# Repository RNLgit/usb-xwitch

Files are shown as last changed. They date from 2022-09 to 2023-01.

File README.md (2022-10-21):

# USB Hub

A programmable budget USB 1:2 multiplexer and HUB device (original name usb-xwitch). Features one 1:2 USB 3.1 switch and 4 Ch USB 2.0 remote 
controllable HUB. Controlling via on board micro USB or by Raspberry Pi UART. 

## CAD Setup (KiCad 6.0)

- Open ./sch/usb_xwitch.kicad_pro -> Schematics Editor 
- in Preferences -> Configure Path, add path name: "USB_XWITCH" and path: absolute address of the project (e.g. /Users/runnanl/src/usb-hub)

1. Channel Features

- Switch: USB 3.0 High Speed 1 Mux 2 switching. Additional physical control by push button switch.
- HUB: USB 2.0 HS 1:4 HUB. Individual remote control, power delivery and over current shutdown.
- HUB Expansion: UART daisy chain HUB capability.

2. Command via micro USB serial (default) or use by UART from Raspberry Pi (as a HAT)

## CAD Setup (KiCad 6.0)

- Open ./sch/usb_xwitch.kicad_pro -> Schematics Editor 
- in Preferences -> Configure Path, add path name: "USB_XWITCH" and path: absolute address of the project (e.g. /Users/runnanl/src/usb-hub)

## Hardware Overview

version: v0.2

PCBA front
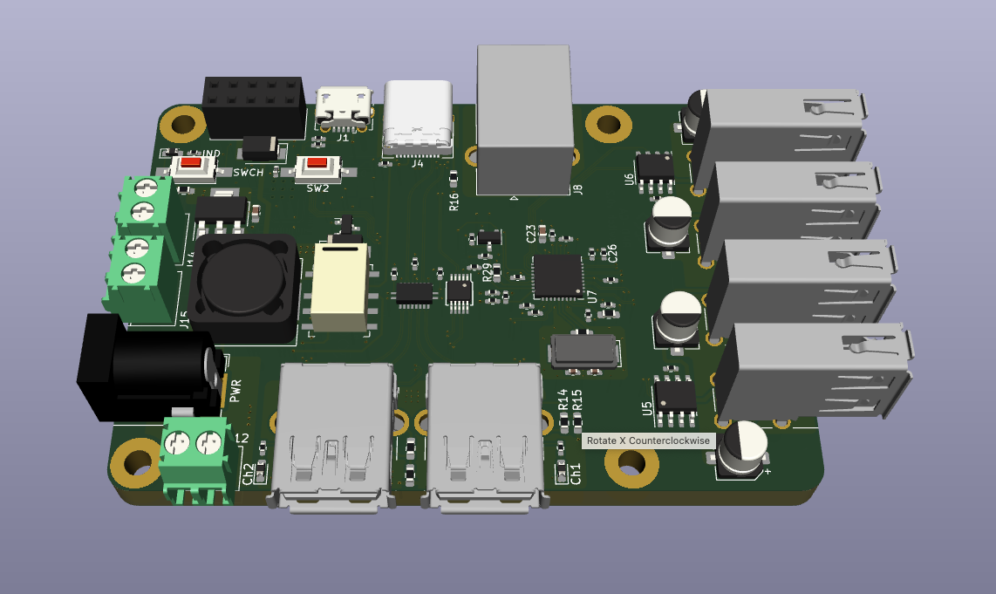
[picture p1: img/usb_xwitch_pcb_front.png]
HardwareOverview (front)


PCBA rear
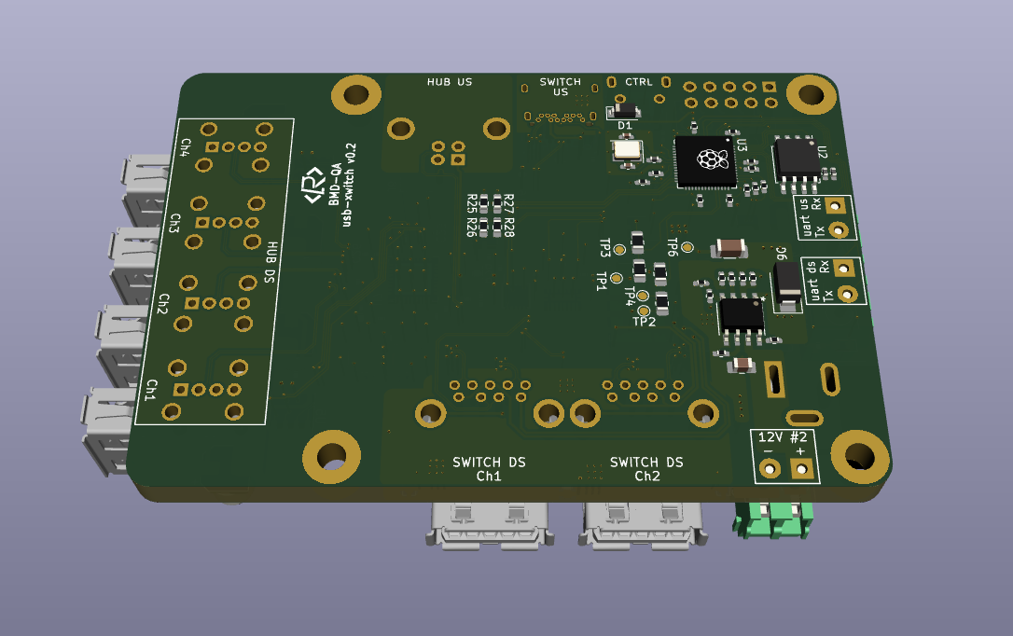
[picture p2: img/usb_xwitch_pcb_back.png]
HardwareOverview (back)


- CHS: USB3.0 1 mux 2. Port active indications. Switch button.
- CHH: USB2.0 HS 1x upstream USB-B to 4x downstream USB-A ports. Control via commands.
- Raspberry Pi compaticable header (10 Pins).
- Mountable as Raspberry Pi 2/3/4 HAT.

Power Supply:

12V 2A supplied by barrel jack (default unmounted) OR PWR screw terminal. Alternatively, 5V 3A DC power can directly
power 5V points from 10 Pin header. 

> **WARNING** : Only one power supply connected at the same time

## Software Overview

- pico software
- USB control protocols and commands
- UART control commands

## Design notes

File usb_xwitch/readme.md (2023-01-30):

# USB-Xwitch Python Package

pico controller and communication package

- pico: code flash to board
- commsrepl: controlling command via pico onboard usb with repl communication over py
- commsrpi: communication via UART header (J8) to raspberry pi

## Flash pico controller

Flash pico uses python ```rshell``` to copy files into internal memory

use rshell to flash ./pico files to the board
1. ```pip install rshell``` (need to be in Python environment)
2. ```rshell -p port_name``` (or simply ```rshell``` if this is the only board connected)
    
   e.g.:
   
    Windows: ```rshell -p COMX```

   Linux / macOS: ```rshell -p /dev/tty.usbmodem11201```

3. Copy firmware files:
    - ```cp main.py /pyboard/main.py```
    - ```cp conf.py /pyboard/conf.py```
5. power cycle pico

   ### validation
   1. connect to pico 
      
      Windows: putty -> Serial --> COM port and connect
      
      macOS: ```minicom -D /dev/tty.usbmodem1234546```
   
   2. flip on off of pico onboard led. Visual check on board.
      ```console
      >>> flip_indicator_led()
      ```
   
## Communications

1. Direct commanding over serial 
    - macOS
      - install ```minicom``` (```brew install minicom```)
      - get divece name by: ```ls /dev/tty*```
      - connect device by: ```minicom -D /dev/tty.usbmodel123456```
      - enjoy!
    - Windows
      - install PuTTY
      - open PuTTY, go to serial, enter board port COMx appear in device manager
      - enjoy!
2. As a python package (under construction)
    - install python package 
    ```pip install -e ./usb_xwitch/comms-repl```
    - Working in progress...

## Commands

Commands available via ``` print(__doc__)``` when communication established

Single hub functions:

```set_hub(list)```: set hub 4 channels on/off. format: ```[bool, bool, bool, bool]```

```get_hub()```: get current hub 4 channels in tuple

```set_switch(int)```: set switch to channel 1 / 2. starting from 0

```get_switch()```: get current switch channel

```get_adc(int)```: get current switch bus 1 / 2 volrage reading

```flip_indicator_led()```: flip indicator led to opposite state

```ind_led(bool)```: bool. set indicator led status

Daisy chain hub functions:

```discovery_chain()```: use currrent hub as root hub, discovery all available downstream daisychain-able hubs

```set_hub_chain(*args)```: set daisy chain hubs on/off (bool list). None to escape. e.g. set_hub_chain([True, False, False], None, [True, True, True, True]) set hub0 channel 1 on, channel 2 and 3 off (channel 4 used to chain next hub); keep hub1 unchanged; set hub2 all 4 channels on.

```set_hubs(bool)```: set all hub channels on the chain on / off, except for the channel used for chaining next hub. (default ch4)

```get_hubs()```: get all hubs on off status in a dictionary. dictionary syntax: {channel_no: [bool_list]}

```get_hub_chain(int)```: get a hub channel on off status list by its index number. root hub index starting from 0

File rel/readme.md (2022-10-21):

Release and manufacturing directory.

## Directory guide:

- bom_x: BoM file with fields of: Comment, Designator, Footprint, LCSC (pcba manufacturer specific)
- gerber_x: gerber files, drill files, drill map files
- cpl_x: component placement files for PCBA. Fields: Designator, Val, Package, Mid X, Mid Y, Rotation, Layer

## Fabrication Generation Guide:

- Follow the [guide](https://support.jlcpcb.com/article/194-how-to-generate-gerber-and-drill-files-in-kicad-6) to generate gerber and drill
- Follow the [guide](https://support.jlcpcb.com/article/84-how-to-generate-the-bom-and-centroid-file-from-kicad) to generate BoM and CPL for PCBA

## Uploading:

- zip gerber into single file and upload
- upload bom file if required PCBA
- upload cpl file if required PCBA

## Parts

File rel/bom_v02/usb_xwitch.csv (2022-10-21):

Comment | Designator | Footprint | LCSC part number
100n | C1,C2,C3,C4,C5,C6,C7,C8,C9,C10,C11,C18,C19,C20,C21,C22,C24,C25,C27,C28,C29,C30,C37,C38,C41 | Resistor_SMD:R_0402_1005Metric_Pad0.72x0.64mm_HandSolder | C1525
1u | C12,C13,C26,C32 | Resistor_SMD:R_0402_1005Metric_Pad0.72x0.64mm_HandSolder | C52923
2.2u | C14 | Inductor_SMD:L_0402_1005Metric_Pad0.77x0.64mm_HandSolder | C12530
100n | C15 | Inductor_SMD:L_0402_1005Metric_Pad0.77x0.64mm_HandSolder | C1525
30pF | C16,C17 | Capacitor_SMD:C_0402_1005Metric_Pad0.74x0.62mm_HandSolder | C1570
4.7u | C23 | Capacitor_SMD:C_0603_1608Metric_Pad1.08x0.95mm_HandSolder | C19666
100u | C31,C33,C36,C40 | Capacitor_SMD:CP_Elec_5x5.4 | C87867
27p | C35,C39 | Capacitor_SMD:C_0402_1005Metric_Pad0.74x0.62mm_HandSolder | C1557
22u | C42 | Capacitor_SMD:C_1206_3216Metric_Pad1.33x1.80mm_HandSolder | C12891
10u | C43 | Capacitor_SMD:C_0805_2012Metric_Pad1.18x1.45mm_HandSolder | C440198
150pF | C44 | Resistor_SMD:R_0402_1005Metric_Pad0.72x0.64mm_HandSolder | C1527
10u | C45,C46 | Capacitor_SMD:C_0603_1608Metric_Pad1.08x0.95mm_HandSolder | C96446
B5819W SL | D1 | Diode_SMD:D_SOD-123 | C8598
19-217/GHC-YR1S2/3T | D2,D4,D5,D8,D9,D10,D11,D12 | Diode_SMD:D_0603_1608Metric_Pad1.05x0.95mm_HandSolder | C72043
SS34 | D3,D6,D7 | Diode_SMD:D_SMA | C8678
RPI Mounting Hole | H1,H2,H3,H4 | MountingHole:MountingHole_3.2mm_M3_Pad
USB_B_Micro | J1 | Connector_USB:USB_Micro-B_Molex-105017-0001 | C10418
DNF | J11 | Connector_PinHeader_1.00mm:PinHeader_1x04_P1.00mm_Vertical_SMD_Pin1Left
Screw_Terminal_3.5mm | J12,J14,J15 | TerminalBlock_4Ucon:TerminalBlock_4Ucon_1x02_P3.50mm_Horizontal | C466970
Conn_02x05_Odd_Even | J13 | Connector_PinSocket_2.54mm:PinSocket_2x05_P2.54mm_Vertical
Barrel_Jack_Switch_Pin3Ring | J2 | usb_xwitch:BarrelJack_SCD556DCS113BM3G
USB3_A | J3,J5 | usb_xwitch:USB3_A_AdamTech_USB-A3-S-RA | C69073
USB_C_Receptacle | J4 | usb_xwitch:USB_TypeC_24Pin_ShouHan | C456013
USB_A | J6,J7,J9,J10 | Connector_USB:USB_A_Wuerth_614004134726_Horizontal | C720524
USB_B | J8 | Connector_USB:USB_B_OST_USB-B1HSxx_Horizontal | C46393
Relay_DPDT_Panasonic_AGQ200A4H | K1 | usb_xwitch:Relay_DPDT_Panasonic_AGQ200A4H | C490150
15u | L1 | Inductor_SMD:L_12x12mm_H6mm | C169384
PI3USB302-A | MUX1 | usb_xwitch:USB_MUX_DEMUX_PI3USB302-A | C500787
2N7002P | Q1,Q2 | Package_TO_SOT_SMD:SOT-23 | C8545
27.4R | R1,R2 | Resistor_SMD:R_0402_1005Metric_Pad0.72x0.64mm_HandSolder | C31439
18K | R10,R11 | Resistor_SMD:R_0805_2012Metric_Pad1.20x1.40mm_HandSolder | C17506
33K | R12,R13 | Resistor_SMD:R_0805_2012Metric_Pad1.20x1.40mm_HandSolder | C17633
0R | R14,R15,R16,R17,R18 | Resistor_SMD:R_0603_1608Metric_Pad0.98x0.95mm_HandSolder | C21189
100K | R19,R20,R21,R24,R30,R33,R35 | Resistor_SMD:R_0402_1005Metric_Pad0.72x0.64mm_HandSolder | C25741
12K | R22 | Resistor_SMD:R_0603_1608Metric_Pad0.98x0.95mm_HandSolder | C22790
1M | R23 | Resistor_SMD:R_0603_1608Metric_Pad0.98x0.95mm_HandSolder | C22935
100K | R27,R28 | Resistor_SMD:R_0603_1608Metric_Pad0.98x0.95mm_HandSolder | C25803
1K | R3,R4 | Inductor_SMD:L_0402_1005Metric_Pad0.77x0.64mm_HandSolder | C11702
24.9k | R31 | Resistor_SMD:R_0402_1005Metric_Pad0.72x0.64mm_HandSolder | C226371
210k | R32 | Resistor_SMD:R_0402_1005Metric_Pad0.72x0.64mm_HandSolder | C58827
40.2K | R34 | Resistor_SMD:R_0402_1005Metric_Pad0.72x0.64mm_HandSolder | C137983
510 | R40 | Resistor_SMD:R_0402_1005Metric_Pad0.72x0.64mm_HandSolder | C25123
DNF | C34,R41,R42,R43,R44,R45,R46,R47,R48 | Resistor_SMD:R_0402_1005Metric_Pad0.72x0.64mm_HandSolder
DNF | R49 | Resistor_SMD:R_0603_1608Metric_Pad0.98x0.95mm_HandSolder
470R | R5 | Resistor_SMD:R_0402_1005Metric_Pad0.72x0.64mm_HandSolder | C25117
10K | R6,R25,R26,R29 | Resistor_SMD:R_0603_1608Metric_Pad0.98x0.95mm_HandSolder | C25804
330 | R7,R8,R36,R37,R38,R39 | Resistor_SMD:R_0402_1005Metric_Pad0.72x0.64mm_HandSolder | C25104
56K | R9 | Resistor_SMD:R_0402_1005Metric_Pad0.72x0.64mm_HandSolder | C25796
C2689642 | SW1,SW2 | usb_xwitch:SW_SPST_CK_PTS636_SP43_SMTR | C2689642
TestPoint | TP1,TP2,TP3,TP4,TP6 | TestPoint:TestPoint_Pad_D1.0mm
W25Q64JVSSIQ | U2 | Package_SO:SOIC-8_5.23x5.23mm_P1.27mm | C83140
RP2040 | U3 | usb_xwitch:RP2040-QFN-56 | C2040
FSUSB42MUX | U4 | Package_SO:MSOP-10_3x3mm_P0.5mm | C11355
MIC2026-1BM | U5,U6 | Package_SO:SOIC-8_3.9x4.9mm_P1.27mm | C144190
USB2514B_Bi | U7 | Package_DFN_QFN:QFN-36-1EP_6x6mm_P0.5mm_EP3.7x3.7mm | C58940
MP1584EN-LF-Z | U8 | usb_xwitch:MP1584EN-LF-Z | C15051
NCP1117LPST33T3G | U9 | Package_TO_SOT_SMD:SOT-223-3_TabPin2 | C146799
12MHz | Y1 | Crystal:Crystal_SMD_3225-4Pin_3.2x2.5mm | C9002
24MHz | Y2 | Crystal:Crystal_SMD_5032-2Pin_5.0x3.2mm_HandSoldering | C112570

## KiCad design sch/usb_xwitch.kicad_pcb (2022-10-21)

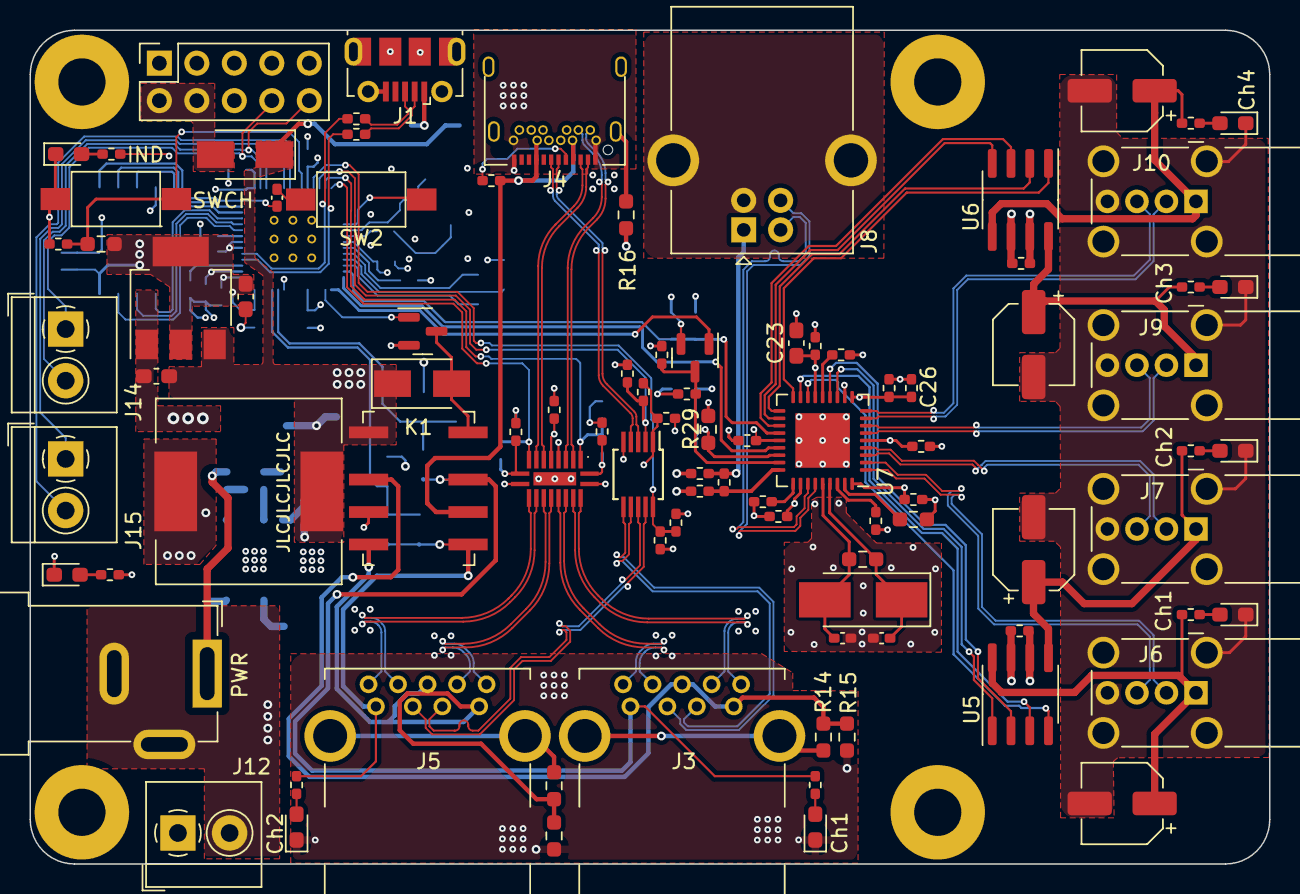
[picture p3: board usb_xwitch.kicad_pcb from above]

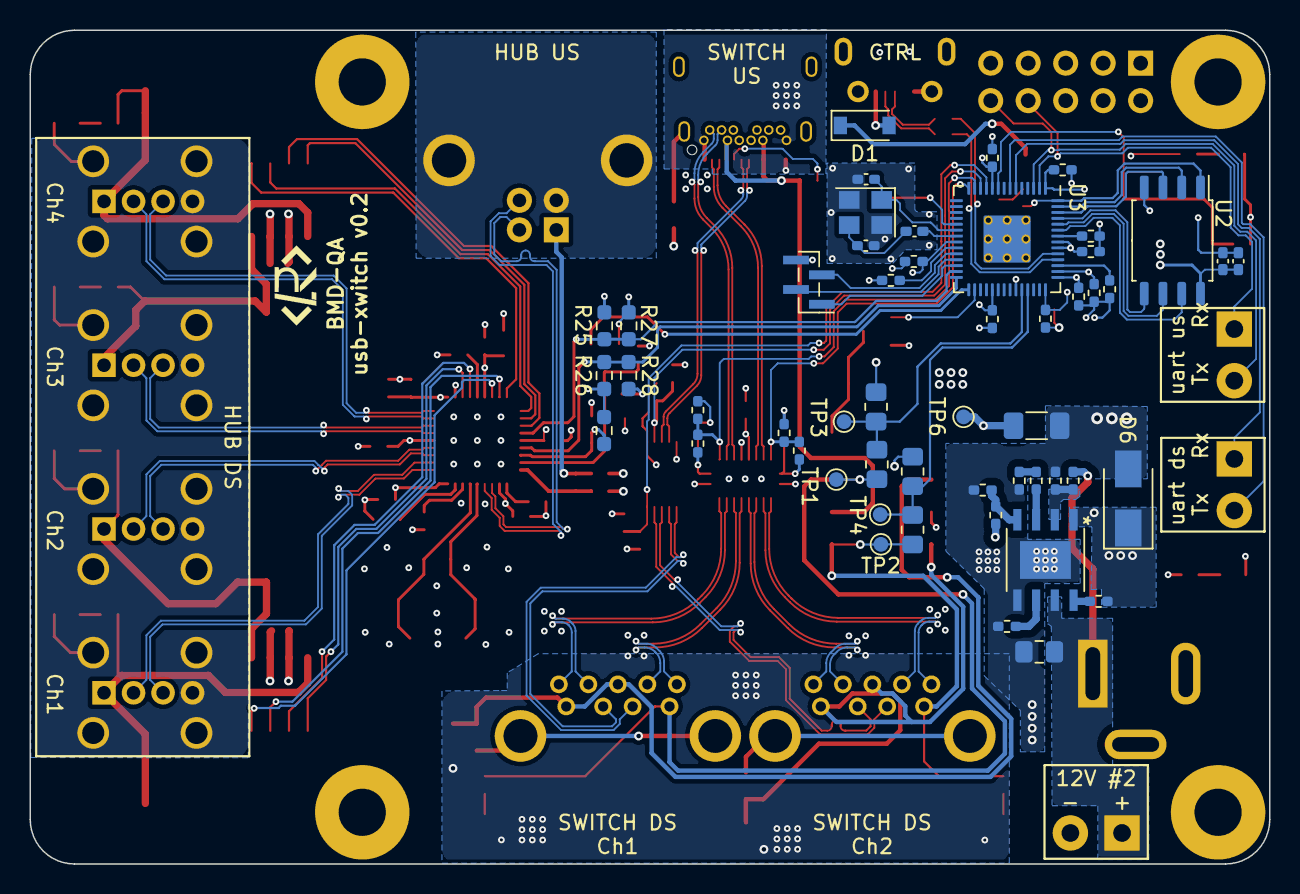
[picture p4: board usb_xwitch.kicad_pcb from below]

Board: 4 copper layers, 84.0 x 56.5 mm, 148 parts (51 on the bottom side), 115 nets.

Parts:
C1, C2, C3, C4, C5, C6, C7, C8, C9, C10, C11, C18, C19, C20, C21, C22, C24, C25, C27, C28, C29, C30, C37, C38, C41: 100n; R_0402_1005Metric_Pad0.72x0.64mm_HandSolder
C12, C13, C26, C32: 1u; R_0402_1005Metric_Pad0.72x0.64mm_HandSolder
C14: 2.2u; L_0402_1005Metric_Pad0.77x0.64mm_HandSolder
C15: 100n; L_0402_1005Metric_Pad0.77x0.64mm_HandSolder
C16, C17: 30pF; C_0402_1005Metric_Pad0.74x0.62mm_HandSolder
C23: 4.7u; C_0603_1608Metric_Pad1.08x0.95mm_HandSolder
C31, C33, C36, C40: 100u; CP_Elec_5x5.4
C34: DNF; R_0402_1005Metric_Pad0.72x0.64mm_HandSolder
C35, C39: 27p; C_0402_1005Metric_Pad0.74x0.62mm_HandSolder
C42: 22u; C_1206_3216Metric_Pad1.33x1.80mm_HandSolder
C43: 10u; C_0805_2012Metric_Pad1.18x1.45mm_HandSolder
C44: 150pF; R_0402_1005Metric_Pad0.72x0.64mm_HandSolder
C45, C46: 10u; C_0603_1608Metric_Pad1.08x0.95mm_HandSolder
D1: B5819W SL; D_SOD-123
D2, D4, D5, D8, D9, D10, D11, D12: 19-217/GHC-YR1S2/3T; D_0603_1608Metric_Pad1.05x0.95mm_HandSolder
D3, D6, D7: SS34; D_SMA
H1, H2, H3, H4: RPI Mounting Hole; MountingHole_3.2mm_M3_Pad
J1: USB_B_Micro; USB_Micro-B_Molex-105017-0001
J2: Barrel_Jack_Switch_Pin3Ring; BarrelJack_SCD556DCS113BM3G
J3, J5: USB3_A; USB3_A_AdamTech_USB-A3-S-RA
J4: USB_C_Receptacle; USB_TypeC_24Pin_ShouHan
J6, J7, J9, J10: USB_A; USB_A_Wuerth_614004134726_Horizontal
J8: USB_B; USB_B_OST_USB-B1HSxx_Horizontal
J11: DNF; PinHeader_1x04_P1.00mm_Vertical_SMD_Pin1Left
J12, J14, J15: Screw_Terminal_3.5mm; TerminalBlock_4Ucon_1x02_P3.50mm_Horizontal
J13: Conn_02x05_Odd_Even; PinSocket_2x05_P2.54mm_Vertical
K1: Relay_DPDT_Panasonic_AGQ200A4H
L1: 15u; L_12x12mm_H6mm
MUX1: PI3USB302-A; USB_MUX_DEMUX_PI3USB302-A
Q1, Q2: 2N7002P; SOT-23
R1, R2: 27.4R; R_0402_1005Metric_Pad0.72x0.64mm_HandSolder
R3, R4: 1K; L_0402_1005Metric_Pad0.77x0.64mm_HandSolder
R5: 470R; R_0402_1005Metric_Pad0.72x0.64mm_HandSolder
R6, R25, R26, R29: 10K; R_0603_1608Metric_Pad0.98x0.95mm_HandSolder
R7, R8, R36, R37, R38, R39: 330; R_0402_1005Metric_Pad0.72x0.64mm_HandSolder
R9: 56K; R_0402_1005Metric_Pad0.72x0.64mm_HandSolder
R10, R11: 18K; R_0805_2012Metric_Pad1.20x1.40mm_HandSolder
R12, R13: 33K; R_0805_2012Metric_Pad1.20x1.40mm_HandSolder
R14, R15, R16, R17, R18: 0R; R_0603_1608Metric_Pad0.98x0.95mm_HandSolder
R19, R20, R21, R24, R30, R33, R35: 100K; R_0402_1005Metric_Pad0.72x0.64mm_HandSolder
R22: 12K; R_0603_1608Metric_Pad0.98x0.95mm_HandSolder
R23: 1M; R_0603_1608Metric_Pad0.98x0.95mm_HandSolder
R27, R28: 100K; R_0603_1608Metric_Pad0.98x0.95mm_HandSolder
R31: 24.9k; R_0402_1005Metric_Pad0.72x0.64mm_HandSolder
R32: 210k; R_0402_1005Metric_Pad0.72x0.64mm_HandSolder
R34: 40.2K; R_0402_1005Metric_Pad0.72x0.64mm_HandSolder
R40: 510; R_0402_1005Metric_Pad0.72x0.64mm_HandSolder
R41, R42, R43, R44, R45, R46, R47, R48: DNF; R_0402_1005Metric_Pad0.72x0.64mm_HandSolder
R49: DNF; R_0603_1608Metric_Pad0.98x0.95mm_HandSolder
SW1, SW2: C2689642; SW_SPST_CK_PTS636_SP43_SMTR
TP1, TP2, TP3, TP4, TP6: TestPoint; TestPoint_Pad_D1.0mm
U2: W25Q64JVSSIQ; SOIC-8_5.23x5.23mm_P1.27mm
U3: RP2040; RP2040-QFN-56
U4: FSUSB42MUX; MSOP-10_3x3mm_P0.5mm
U5, U6: MIC2026-1BM; SOIC-8_3.9x4.9mm_P1.27mm
U7: USB2514B_Bi; QFN-36-1EP_6x6mm_P0.5mm_EP3.7x3.7mm
U8: MP1584EN-LF-Z
U9: NCP1117LPST33T3G; SOT-223-3_TabPin2
Y1: 12MHz; Crystal_SMD_3225-4Pin_3.2x2.5mm
Y2: 24MHz; Crystal_SMD_5032-2Pin_5.0x3.2mm_HandSoldering

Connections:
+1V1: C1.1, C2.1, C13.1, U3.23 (DVDD), U3.45 (VREG_VOUT), U3.50 (DVDD)
+3V3: C3.1, C4.1, C5.1, C6.1, C7.1, C8.1, C9.1, C10.1, C11.1, C12.1, C14.1, C15.1, C19.1, C20.1, C23.1, C24.1, C25.1, C26.1, C27.1, C28.1, C29.1, C30.1, C46.1, MUX1.1 (VDD), MUX1.6 (VDD), MUX1.10 (VDD), R6.1, R21.2, R25.1, R26.1, R41.1, R42.1, R45.1, R46.1, R49.1, U2.8 (VCC), U3.1 (IOVDD), U3.10 (IOVDD), U3.22 (IOVDD), U3.33 (IOVDD), U3.42 (IOVDD), U3.43 (ADC_AVDD), U3.44 (VREG_IN), U3.48 (USB_VDD), U3.49 (IOVDD), U4.1 (VCC), U7.5 (VDDA33), U7.10 (VDDA33), U7.15 (VDD33), U7.23 (VDD33), U7.29 (VDDA33), U7.36 (VDDA33), U9.2 (VO)
+5V: C21.1, C22.1, C42.1, C45.1, D1.1 (K), D3.1 (K), D7.1 (K), K1.1, L1.2, R32.1, R40.1, TP6.1, U5.7 (IN), U6.7 (IN), U9.3 (VI)
/UART_RX_DN: J15.1, U3.6 (GPIO4)
/UART_RX_UP: J13.8, J14.1, U3.2 (GPIO0)
/UART_TX_DN: J15.2, U3.7 (GPIO5)
/UART_TX_UP: J13.10, J14.2, U3.3 (GPIO1)
/power_and_io/PWR_IN: C43.1, J2.1, J12.1, R30.2, U8.7 (VIN)
/usb2_hub/H_CTL_N: C39.1, R23.1, U7.32 (XTALOUT), Y2.2
/usb2_hub/H_CTL_P: C35.1, R23.2, U7.33 (XTALIN/CLKIN), Y2.1
/usb2_hub/H_D1_N: J6.2 (D-), U7.1 (USBDM_DN1/PRT_DIS_M1)
/usb2_hub/H_D1_P: J6.3 (D+), U7.2 (USBDP_DN1/PRT_DIS_P1)
/usb2_hub/H_D2_N: J7.2 (D-), U7.3 (USBDM_DN2/PRT_DIS_M2)
/usb2_hub/H_D2_P: J7.3 (D+), U7.4 (USBDP_DN2/PRT_DIS_P2)
/usb2_hub/H_D3_N: J9.2 (D-), U7.6 (USBDM_DN3/PRT_DIS_M3)
/usb2_hub/H_D3_P: J9.3 (D+), U7.7 (USBDP_DN3/PRT_DIS_P3)
/usb2_hub/H_D4_N: J10.2 (D-), U7.8 (USBDM_DN4/PRT_DIS_M4)
/usb2_hub/H_D4_P: J10.3 (D+), U7.9 (USBDP_DN4/PRT_DIS_P4)
/usb2_hub/H_U_N: J8.3 (D+), U7.31 (USBDP_UP)
/usb2_hub/H_U_P: J8.2 (D-), U7.30 (USBDM_UP)
/usb2_hub/OCSn1: U5.2 (FLGA), U7.13 (OCS_N1)
/usb2_hub/OCSn2: U5.3 (FLGB), U7.17 (OCS_N2)
/usb2_hub/OCSn3: U6.2 (FLGA), U7.19 (OCS_N3)
/usb2_hub/OCSn4: U6.3 (FLGB), U7.21 (OCS_N4)
/usb2_hub/PRTPWR1: U5.1 (ENA), U7.12 (PRTPWR1/BC_EN1)
/usb2_hub/PRTPWR2: U5.4 (ENB), U7.16 (PRTPWR2/BC_EN2)
/usb2_hub/PRTPWR3: U6.1 (ENA), U7.18 (PRTPWR3/BC_EN3)
/usb2_hub/PRTPWR4: U6.4 (ENB), U7.20 (PRTPWR4/BC_EN4)
/usb2_hub/RESETn: C34.1, Q2.3 (D), R21.1, U7.26 (RESET_N)
/usb2_hub/RST_CTL: Q2.1 (G), U3.29 (GPIO18)
/usb2_hub/SCL: R26.2, R28.1, U3.28 (GPIO17), U7.24 (SCL/SMBCLK/CFG_SEL0)
/usb2_hub/SDA: R25.2, R27.1, U3.27 (GPIO16), U7.22 (SDA/SMBDATA/NON_REM1)
/usb2_hub/V_Ch1: C31.1, J6.1 (VBUS), R36.1, U5.8 (OUTA)
/usb2_hub/V_Ch2: C33.1, J7.1 (VBUS), R37.1, U5.5 (OUTB)
/usb2_hub/V_Ch3: C36.1, J9.1 (VBUS), R38.1, U6.8 (OUTA)
/usb2_hub/V_Ch4: C40.1, J10.1 (VBUS), R39.1, U6.5 (OUTB)
/usb3_switch/PD-SU2: R45.2, R47.1, U3.11 (GPIO8), U4.10 (~OE)
/usb3_switch/PD-SU3: MUX1.2 (PD), R41.2, R43.1, U3.13 (GPIO10)
/usb3_switch/REL-CTL: Q1.1 (G), U3.30 (GPIO19)
/usb3_switch/RL1: D3.2 (A), K1.8, Q1.3 (D)
/usb3_switch/SD_1D_N: J3.2 (D-), U4.6 (HSD1-)
/usb3_switch/SD_1D_P: J3.3 (D+), U4.7 (HSD1+)
/usb3_switch/SD_1RX_N: J3.5 (SSRX-), MUX1.18 (Tx1-)
/usb3_switch/SD_1RX_P: J3.6 (SSRX+), MUX1.19 (Tx1+)
/usb3_switch/SD_1TX_N: J3.8 (SSTX-), MUX1.16 (Rx1-)
/usb3_switch/SD_1TX_P: J3.9 (SSTX+), MUX1.17 (Rx1+)
/usb3_switch/SD_2D_N: J5.2 (D-), U4.8 (HSD2-)
/usb3_switch/SD_2D_P: J5.3 (D+), U4.9 (HSD2+)
/usb3_switch/SD_2RX_N: J5.5 (SSRX-), MUX1.14 (Tx2-)
/usb3_switch/SD_2RX_P: J5.6 (SSRX+), MUX1.15 (Tx2+)
/usb3_switch/SD_2TX_N: J5.8 (SSTX-), MUX1.12 (Rx2-)
/usb3_switch/SD_2TX_P: J5.9 (SSTX+), MUX1.13 (Rx2+)
/usb3_switch/SEL-SU2: R46.2, R48.1, U3.12 (GPIO9), U4.2 (SEL)
/usb3_switch/SEL-SU3: MUX1.9 (SEL), R42.2, R44.1, U3.14 (GPIO11)
/usb3_switch/SU_D_N: J4.A7 (D-), U4.4 (D-)
/usb3_switch/SU_D_P: J4.A6 (D+), U4.3 (D+)
/usb3_switch/SU_R1_N: J4.B10 (RX1-), MUX1.4 (Tx-)
/usb3_switch/SU_R1_P: J4.B11 (RX1+), MUX1.3 (Tx+)
/usb3_switch/SU_T1_N: J4.A3 (TX1-), MUX1.8 (Rx-)
/usb3_switch/SU_T1_P: J4.A2 (TX1+), MUX1.7 (Rx+)
/usb3_switch/SW-INTR: C18.1, R6.2, SW1.2 (B), U3.9 (GPIO7)
/usb3_switch/VBUS_1_1: J3.1 (VBUS), K1.7, R7.1, R10.1, TP1.1
/usb3_switch/VBUS_1_2: J5.1 (VBUS), K1.5, R8.1, R11.1, TP2.1
/usb3_switch/V_1_1: R10.2, R12.1, TP3.1, U3.38 (GPIO26_ADC0)
/usb3_switch/V_1_2: R11.2, R13.1, TP4.1, U3.39 (GPIO27_ADC1)
/xwitch_controller/GPIO25_LED: R5.1, U3.37 (GPIO25)
/xwitch_controller/QSPI_SCLK: U2.6 (CLK), U3.52 (QSPI_SCLK)
/xwitch_controller/QSPI_SD0: U2.5 (DI(IO0)), U3.53 (QSPI_SD0)
/xwitch_controller/QSPI_SD1: U2.2 (DO(IO1)), U3.55 (QSPI_SD1)
/xwitch_controller/QSPI_SD2: U2.3 (IO2), U3.54 (QSPI_SD2)
/xwitch_controller/QSPI_SD3: U2.7 (IO3), U3.51 (QSPI_SD3)
/xwitch_controller/QSPI_SS: R3.1, U2.1 (~CS), U3.56 (QSPI_SS)
/xwitch_controller/RUN: J11.1, U3.26 (RUN)
/xwitch_controller/SWCLK: J11.3, U3.24 (SWCLK)
/xwitch_controller/SWD: J11.2, U3.25 (SWD)
/xwitch_controller/USB_D+: J1.3 (D+), R1.2
/xwitch_controller/USB_D-: J1.2 (D-), R2.2
/xwitch_controller/XIN: C16.1, U3.20 (XIN), Y1.1
/xwitch_controller/XOUT: R4.1, U3.21 (XOUT)
GND: C1.2, C2.2, C3.2, C4.2, C5.2, C6.2, C7.2, C8.2, C9.2, C10.2, C11.2, C12.2, C13.2, C14.2, C15.2, C16.2, C17.2, C18.2, C19.2, C20.2, C21.2, C22.2, C23.2, C24.2, C25.2, C26.2, C27.2, C28.2, C29.2, C30.2, C31.2, C32.2, C33.2, C34.2, C35.2, C36.2, C37.2, C38.2, C39.2, C40.2, C42.2, C43.2, C45.2, C46.2, D2.1 (K), D4.1 (K), D5.1 (K), D6.2 (A), D8.1 (K), D9.1 (K), D10.1 (K), D11.1 (K), D12.1 (K), J1.5 (GND), J1.6 (Shield), J2.2, J2.3, J4.A1 (GND), J4.A12 (GND), J4.B1 (GND), J4.B12 (GND), J6.4 (GND), J6.5 (Shield), J7.4 (GND), J7.5 (Shield), J8.4 (GND), J8.5 (Shield), J9.4 (GND), J9.5 (Shield), J10.4 (GND), J10.5 (Shield), J11.4, J12.2, J13.6, J13.9, K1.3, MUX1.5 (GND), MUX1.11 (GND), MUX1.20 (GND), Q1.2 (S), Q2.2 (S), R12.2, R13.2, R15.2, R16.1, R18.2, R20.1, R22.1, R24.1, R27.2, R28.2, R29.2, R31.2, R33.1, R34.2, R35.1, R43.2, R44.2, R47.2, R48.2, SW1.1 (A), SW2.1 (A), U2.4 (GND), U3.19 (TESTEN), U3.57 (GND), U4.5 (GND), U5.6 (GND), U6.6 (GND), U7.11 (TEST), U7.37 (VSS), U8.5 (GND), U8.EPAD, U9.1 (GND), Y1.2, Y1.4
unnamed: C17.1, R4.2, Y1.3
unnamed: C32.1, J8.1 (VBUS), R19.1
unnamed: C37.1, U7.34 (PLLFILT)
unnamed: C38.1, U7.14 (CRFILT)
unnamed: C41.1, D6.1 (K), L1.1, U8.1 (SW)
unnamed: C41.2, U8.8 (BST)
unnamed: C44.1, U8.3 (COMP)
unnamed: C44.2, R35.2
unnamed: D1.2 (A), J1.1 (VBUS)
unnamed: D2.2 (A), R5.2
unnamed: D4.2 (A), R7.2
unnamed: D5.2 (A), R8.2
unnamed: D7.2 (A), J13.2, J13.4
unnamed: D8.2 (A), R36.2
unnamed: D9.2 (A), R37.2
unnamed: D10.2 (A), R38.2
unnamed: D11.2 (A), R39.2
unnamed: D12.2 (A), R40.2
unnamed: J3.4 (GND), J3.7 (DRAIN), K1.2, R14.2, R15.1
unnamed: J3.10 (SHIELD), R14.1
unnamed: J4.A4 (VBUS), J4.A9 (VBUS), J4.B4 (VBUS), J4.B9 (VBUS), K1.6, R9.1
unnamed: J4.A5 (CC1), R9.2
unnamed: J4.S1 (SHIELD), R16.2
unnamed: J5.4 (GND), J5.7 (DRAIN), K1.4, R17.2, R18.1
unnamed: J5.10 (SHIELD), R17.1
unnamed: R1.1, U3.47 (USB_DP)
unnamed: R2.1, U3.46 (USB_DM)
unnamed: R3.2, SW2.2 (B)
unnamed: R19.2, R20.2, U7.27 (VBUS_DET)
unnamed: R22.2, U7.35 (RBIAS)
unnamed: R24.2, U7.28 (SUSP_IND/LOCAL_PWR/NON_REM0)
unnamed: R30.1, R31.1, U8.2 (EN)
unnamed: R32.2, R34.1, U8.4 (FB)
unnamed: R33.2, U8.6 (FREQ)
unnamed: R29.1, R49.2, U7.25 (HS_IND/CFG_SEL1)

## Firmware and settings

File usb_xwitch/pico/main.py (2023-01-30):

from machine import Pin, ADC, UART, I2C
from conf import HUBAddr, HW, DC, DCMSG
import time
from collections import deque
import _thread

__pcb__ = '0.2'
__version__ = '0.2 a1'
_debug = False

led_ind_stat = False
hub_chain_id = -1
total_hubs = -1
eoc = False  # end of daisy chain flag


def _intr_change_switch(pin) -> None:
    cur = get_switch()
    if cur == 1:
        set_switch(0)
    elif cur == 0:
        set_switch(1)
    else:
        raise ValueError(f'manual channel {cur} invalid position')


def ind_led(en: bool) -> None:
    """
    toggle on off of pico onboard led
    """
    _led_ind.value(en)


def flip_indicator_led() -> None:
    """
    flip indicator led status
    """
    global led_ind_stat
    led_ind_stat = not led_ind_stat
    ind_led(led_ind_stat)


def get_adc(no: int) -> float:
    """
    get adc reading from adc channel
    """
    adc = {1: _adc_a1, 2: _adc_a2}
    if adc.get(no) is None:
        raise ValueError(f'adc {no} invalid')
    return adc.get(no).read_u16() * HW.ADC_REF_V / 65536 / HW.ADC_RATIO


def set_switch(ch_no: int) -> None:
    """
    set usb switch position. switch to 0 or 1 (ch1 or ch2)
    """
    if ch_no not in [0, 1]:
        raise ValueError(f'cannot switch cha to {ch_no} (ch{ch_no+1}). Only 0, 1 (2 channels) supported')
    _sw2_sel.value(ch_no)
    _sw3_sel.value(ch_no)
    _sw_rel.value(ch_no)


def get_switch() -> int:
    """
    get current usb switch position. Expect 1 or 2.
    """
    switch_ctrl = [_sw2_sel.value(), _sw3_sel.value(), _sw_rel.value()]
    if len(set(switch_ctrl)) > 1:  # if not all 0 or all 1
        raise ValueError(f'internal error. ICs selection or Relay selection error. sel_2, sel_3, rel: {switch_ctrl}')
    return switch_ctrl[1]  # return any value from switch list


def discovery_chain() -> int:
    """
    using current hub as daisy chain root hub, discovery downstream daisy chain hubs

    return total hubs available on the chain (include current hub)
    """
    return _uart.dc_broadcast()


def set_hub(on_off_lst: list) -> None:
    """
    set usb hub channels using a list of bool values.
    e.g. set_hub([False, True, True, False]) set hub channel 2 & 3 on and 1 & 4 off
    """
    if len(on_off_lst) != 4:
        raise ValueError('on off list should be a length of 4 (channels)')
    _hub.reset()
    _hub._init_hub()
    vals = [v for k, v in zip(on_off_lst, HUBAddr.PORTS_MASK) if not k]
    _hub._bw(HUBAddr.PORT_DISABLE_SELF.addr, [sum(vals)])
    _hub.attach()


def set_hub_chain(*args) -> None:
    """
    set hub channel on off in chain giving its id. id as kwargs name and bool list as argument.
    syntax:
        - None to escape hub stat and remain current channel setting.
        - args represents hub index in order
        - each args accpet a bool list that contains on off status of its channel. 3 values accpeted except for
            the last channek which has 4 values (no next hub using one channel for daisy chain)
    e.g.:
        >>> set_hub_chain(None, [1,0,0])  # set 2nd hub (hub id 1) channel 1 on, 2 & 3 off, first hub unchanged (None). 
        Where channel 4 used for connecting next chain hub.
        >>> set_hub_chain(None, None, [0, 1, 0, 1])  # set 3rd hub (id 2) channel 2 & 4 on, 1 & 3 off. Total 3 hubs in 
        the chain.
    """
    if len(args) > total_hubs:
        raise IndexError(f"trying to set hub outside range. total hubs: {total_hubs}")
    for i in reversed(range(len(args))):  # from furtherest chain avoid been cycled by upstream
        if args[i]:
            if i == 0:  # daisy chain root hub
                args[i].insert(DC.DC_CH, True)  # channel to chain next hub should always set on
                set_hub(args[i])
                continue
            is_rtn_received = False
            if _debug: print(f"DaisyChain: SET_HUB: args: {args}, i: {i}")
            if len(args[i]) > len(DC.CHANNEL_MSKS) - 1 and i + 1 < total_hubs:
                raise IndexError(f"Too many channels to set hub: {i}. (mid-chain hubs need one channel for next hub)")
            _uart.send_downstream(DC.make_data(DC.SET_HUB, i,
                                               sum([ch for ch_on, ch in zip(args[i], DC.CHANNEL_MSKS) if ch_on])))
            start_ms = time.ticks_ms()
            while time.ticks_ms() - start_ms < DC.BROADCAST_TIMEOUT:  # may take longer than 1s to reset ic
                if len(_uart.q_msg) > 0:
                    msg = _uart.q_msg.popleft()
                    if hasattr(msg, "cmd"):
                        if msg.cmd == DC.SET_HUB_RTN and int(msg.hub_no) == int(i) and msg.hub_stat == DC.ACK:
                            if _debug: print(f"DaisyChain: SET_HUB_RTN message: {msg}")
                            is_rtn_received = True
                            break
            if is_rtn_received:
                continue
            raise ValueError(f"trying to set hub: {i} in chain with no ack response")


def set_hubs(on_off: bool) -> None:
    """
    set all hubs on chain to all on or all off state
    """
    bool_lst = [[on_off] * (len(DC.CHANNEL_MSKS) - 1) for i in range(total_hubs - 1)]
    bool_lst.append([on_off] * len(DC.CHANNEL_MSKS))
    set_hub_chain(*bool_lst)


def get_hub() -> tuple:
    """
    get usb hub current channels status in tuple of bools.
    """
    data = _hub._br(HUBAddr.PORT_DISABLE_SELF.addr)[1]
    return not bool(data & HUBAddr.PORT_MSK_1), not bool(data & HUBAddr.PORT_MSK_2), \
        not bool(data & HUBAddr.PORT_MSK_3), not bool(data & HUBAddr.PORT_MSK_4)


def get_hubs() -> dict:
    """
    get available hubs all port status in dict
    """
    if hub_chain_id < 0:
        raise ValueError("HUB in standalone mode. Connect daisy chain and use dc_broadcast before use this function.")
    hub_dict = {}
    for id in range(total_hubs):
        hub_dict[id] = get_hub_chain(id)
    return hub_dict


def get_hub_chain(hub_id: int) -> list:
    """
    get hub channel on/off status on daisy chain
    """
    if hub_id == hub_chain_id:  # when querying current hub, not returning the channel used for daisy chain
        return [x for i, x in enumerate(get_hub()) if i != DC.DC_CH]
    _uart.send_downstream(DC.make_data(DC.GET_HUB, hub_id, DC.DATA_DEF))
    start_ms = time.ticks_ms()
    while time.ticks_ms() - start_ms < DC.END_CHAIN_TIMEOUT:
        if len(_uart.q_msg) > 0:
            msg = _uart.q_msg.popleft()
            if hasattr(msg, "cmd"):
                if msg.cmd == DC.GET_HUB_RTN:
                    if _debug: print(f"DaisyChain: get downstream chain stat: {msg}")
                    assert msg.hub_no == hub_id
                    if msg.hub_stat == DC.ERROR:
                        raise OSError(f"hub id:{hub_id} not activated yet. Please check it it is connected")
                    ch1to3 = [bool(DC.CHANNEL_MSK_1 & msg.hub_stat), bool(DC.CHANNEL_MSK_2 & msg.hub_stat),
                              bool(DC.CHANNEL_MSK_3 & msg.hub_stat)]
                    if hub_id + 1 == total_hubs:  # querying hub is end of chain, have all 4 ports available
                        ch1to3.append(bool(DC.CHANNEL_MSK_4 & msg.hub_stat))
                    return ch1to3
    raise ValueError(f"no downstream hub responding within: {DC.END_CHAIN_TIMEOUT}ms")


class HUBI2C(object):
    """
    USB HUB control
    """
    MAX_BLOCK = 32  # max block read / write size for USB2514B

    def __init__(self, scl_pin=HW.HUB_SCL, sda_pin=HW.HUB_SDA, frequency=400000) -> None:
        self.i2c = I2C(0, scl=Pin(scl_pin), sda=Pin(sda_pin), freq=frequency)
        self._init_hub()
        self.attach()
    
    def _init_hub(self) -> None:
        """
        Configure hub default values. t5 stage in SMBus.
        """
        for reg2init in HUBAddr.INIT_DEFAULT:
            self._bw(reg2init.addr, [reg2init.default_val])
        for reg2init in HUBAddr.MFG_AUX_DEFAULT:
            self._bw(reg2init.addr, [reg2init.default_val])
        for mfg in HUBAddr.MFG_DEFAULT:
            self._bw_lot(mfg.addr, mfg.default_val)

    def _br(self, reg_addr: int, byte_ct=33) -> bytearray:
        """
        Block read. byte_ct max 33 (i.e. ct + max 32 bytes data)
        """
        buf_reg = bytes([reg_addr])
        self.i2c.writeto(HUBAddr.SLAVE, buf_reg, False)
        return self.i2c.readfrom(HUBAddr.SLAVE, byte_ct)

    def _bw(self, reg_addr: int, bytes2write: list) -> None:
        """
        Block write
        """
        data = [reg_addr, len(bytes2write)]
        data.extend(bytes2write)
        bw_data = bytes(data)
        self.i2c.writeto(HUBAddr.SLAVE, bw_data)

    def _bw_lot(self, ref_addr: list, bytes2write: list) -> None:
        """
        Block write a lot longer than expected
        """
        if len(bytes2write) > 32:
            chunks = [bytes2write[i : i+32] for i in range(0, len(bytes2write), 32)]
            for idx in range(len(chunks)):
                self._bw(ref_addr[idx], chunks[idx])
        else:
            self._bw(ref_addr[0], bytes2write)  # Blindly take 1st 
   
    def attach(self) -> None:
        """
        Aply hub configs and make it online
        """
        self._bw(HUBAddr.STAT_CMD.addr, [0x01])

    def reset(self, seconds=1) -> None:
        """
        Reset HUB
        """
        _hub_rst.value(HW.HIGH)
        time.sleep(seconds)
        _hub_rst.value(HW.LOW)
        time.sleep(seconds/2)
        self._init_hub()


class UARTController(object):
    """
    UART to communicate to upstream / downstream devices. Daisy chain function for usb hub
    """
    CRC_KEY = '1101'  # polynomial x^3 + x^2 + x^0
    MSG_SCAN = DC.make_data(DC.SCAN, DC.DATA_DEF, DC.DATA_DEF)

    def __init__(self, tx_upstream: int, rx_upstream: int, tx_downstream: int, rx_downstream: int, baudrate=HW.UART_BAUD):
        self.q_us = deque((), HW.Q_LEN)
        self.uart_us = UART(0, baudrate=baudrate, tx=Pin(tx_upstream), rx=Pin(rx_upstream))
        self.q_ds = deque((), HW.Q_LEN)
        self.uart_ds = UART(1, baudrate=baudrate, tx=Pin(tx_downstream), rx=Pin(rx_downstream))
        self.q_msg = deque((), HW.Q_LEN)
        self.rx_flag = True
        self.q_lock = _thread.allocate_lock()
        _thread.start_new_thread(self.rx_thread, ())
 
    @staticmethod
    def _get_crc_field(bit_str: str, poly_str: str, init_filter_str='0') -> str:
        poly_str = poly_str.lstrip('0')
        initial_pad = (len(poly_str) - 1) * init_filter_str
        input_pad_arr = list(bit_str + initial_pad)
        while '1' in input_pad_arr[:len(bit_str)]:
            cur_shift = input_pad_arr.index('1')
            for i in range(len(poly_str)):
                input_pad_arr[cur_shift + i] = str(int(poly_str[i] != input_pad_arr[cur_shift + i]))
        return ''.join(input_pad_arr)[len(bit_str):]
    
    @staticmethod
    def _check_crc(bit_str: str, poly_str: str, crc_value: str):
        poly_str = poly_str.lstrip('0')
        input_pad_arr = list(bit_str + crc_value)
        while '1' in input_pad_arr[:len(bit_str)]:
            cur_shift = input_pad_arr.index('1')
            for i in range(len(poly_str)):
                input_pad_arr[cur_shift + i] = str(int(poly_str[i] != input_pad_arr[cur_shift + i]))
        return '1' not in ''.join(input_pad_arr)[len(bit_str):]
    
    def _read_data(self, ds_us_obj) -> DCMSG:
        """
        read a daisy chain data outside rx thread function
        """
        if ds_us_obj.any() > 0:
            data = ds_us_obj.read(HW.DATA_SIZE)
            if data[0] != DC.DC_HEADER or len(data) != DC.MSG_LEN:
                return  # invalid ack data return None
            return DCMSG(data, data[1], data[2], data[3], data[4])
        
    def _wait_ds_ack(self):
        """
        wait for next daisy chain downstream hub to ack upstream scan command been sent
        """
        if _debug: print('DaisyChain: waiting downstream ack')
        start_t = time.ticks_ms()
        while time.ticks_ms() - start_t < DC.END_CHAIN_TIMEOUT:
            ack = self._read_data(self.uart_ds)
            if ack:
                if ack.hub_stat == DC.ACK:
                    return True
        return False

    def send_upstream(self, data: bytes, no_crc=True) -> int:
        if data[0] != DC.DC_HEADER or len(data) != DC.MSG_LEN:
            raise ValueError('Invalid daisy chain data')
        return self.uart_us.write(data)

    def send_downstream(self, data: bytes, no_crc=True) -> int:
        if data[0] != DC.DC_HEADER or len(data) != DC.MSG_LEN:
            raise ValueError('Invalid daisy chain data')
        return self.uart_ds.write(data)
    
    def dc_broadcast(self) -> int:
        """
        Initiate a broadcast daisy chain signal to query for avaiable chain-able hubs. The current hub (issuer) will 
        be the first device of the chain.
        """
        self.q_lock.acquire()
        global hub_chain_id
        global total_hubs
        hub_chain_id = 0
        msg_nxt_relay = DC.make_data(DC.SCAN, hub_chain_id, DC.DATA_DEF)
        if _debug: print('DaisyChain: sending broadcasting message to downstream')
        self.send_downstream(msg_nxt_relay)
        time_s = time.ticks_ms()
        if self._wait_ds_ack():
            if _debug: print('DaisyChain: Got ACK from first downstream hub, waiting daisy chain return message')
            while time.ticks_ms() - time_s < DC.BROADCAST_TIMEOUT:
                hubs_data = self._read_data(self.uart_ds)
                if hubs_data:  # prevent checking None
                    if hubs_data.cmd == DC.SCAN_RTN:
                        self.q_lock.release()
                        hub_chain_id = 0
                        total_hubs = hubs_data.hub_no
                        if _debug: print(f'DaisyChain: received return message. Total hubs are: {total_hubs}. This hub index: {hub_chain_id}')
                        return total_hubs  # return back with total number of hubs on chain (starting 0)
        total_hubs = -1
        hub_chain_id = -1
        self.q_lock.release()
        return -1
    
    def msg_relay_broadcast(self, dcmsg: DCMSG) -> int:
        """
        downstream hubs for relaying or returning daisy chain message
        """
        if _debug: print(f'DaisyChain: relaying: {dcmsg}')
        global hub_chain_id
        hub_chain_id = dcmsg.hub_no + 1
        msg_nxt_relay = DC.make_data(DC.SCAN, hub_chain_id, DC.DATA_DEF)
        self.send_downstream(msg_nxt_relay)
        ack_back = DC.make_data(DC.SCAN, DC.DATA_DEF, DC.ACK)
        self.send_upstream(ack_back)
        if not self._wait_ds_ack():  # end of chain found
            dc_rtn_msg = DC.make_data(DC.SCAN_RTN, hub_chain_id + 1, DC.DATA_DEF)  # total + 1 as id starts 0
            self.send_upstream(dc_rtn_msg)
            global total_hubs
            total_hubs = hub_chain_id + 1  # no of end chain hub is total hubs number
            if _debug: print(f'DaisyChain: this hub is end of chain, this hub id: {hub_chain_id}, sending back: {dc_rtn_msg}')
    
    def msg_return_chain(self, dcmsg: DCMSG) -> None:
        """
        returning daisy chain downstream 
        """
        if _debug: print(f'DaisyChain: returnning to upstream: {dcmsg}')
        global total_hubs
        total_hubs = dcmsg.hub_no
        self.send_upstream(dcmsg.raw)
    
    def msg_switch(self, data: bytes) -> None:
        """
        routing message to its owm execution function
        """
        if not data:  # prevent checking None
            return
        if data[0] != DC.DC_HEADER or len(data) != DC.MSG_LEN:
            return
        msg = DCMSG(data, data[1], data[2], data[3], data[4])
        if msg.cmd == DC.SCAN:
            if _debug: print(f'DaisyChain: SCAN: scan downstream message received: {msg}')
            self.msg_relay_broadcast(msg)
        elif msg.cmd == DC.SCAN_RTN:
            if _debug: print(f'DaisyChain: SCAN_RTN: returning upstream message received: {msg}')
            self.msg_return_chain(msg)
        elif msg.cmd == DC.GET_HUB:
            if _debug: print(f"DaisyChain: GET_HUB: request received: {msg}")
            if msg.hub_no == hub_chain_id:
                try:
                    if hub_chain_id + 1 == total_hubs:
                        stat = get_hub()
                    else:  # excluding the channel used for daisy chain next hub
                        stat = [x for i, x in enumerate(get_hub()) if i != DC.DC_CH]
                    self.send_upstream(DC.make_data(DC.GET_HUB_RTN, hub_chain_id, int("".join(str(int(i)) for i in reversed(stat)), 2)))
                except OSError:
                    if _debug: print("DaisyChain: GET_HUB: calling get_hub error. Possibly hub not activated yet")
                    self.send_upstream(DC.make_data(DC.GET_HUB_RTN, hub_chain_id, DC.ERROR))
            else:
                if _debug: print(f"DaisyChain: GET_HUB: {msg} not in scope of current chain, relaying msg to next hub")
                self.send_downstream(msg.raw)
        elif msg.cmd == DC.SET_HUB:
            if _debug: print(f"DaisyChain: SET_HUB: request received: {msg}")
            if msg.hub_no == hub_chain_id:
                if hub_chain_id + 1 == total_hubs:
                    set_lst = [bool(msg.hub_stat & DC.CHANNEL_MSK_1), bool(msg.hub_stat & DC.CHANNEL_MSK_2),
                               bool(msg.hub_stat & DC.CHANNEL_MSK_3), bool(msg.hub_stat & DC.CHANNEL_MSK_4)]
                    set_hub(set_lst)
                    self.send_upstream(DC.make_data(DC.SET_HUB_RTN, hub_chain_id, DC.ACK))
                else:
                    set_lst = [bool(msg.hub_stat & DC.CHANNEL_MSK_1), bool(msg.hub_stat & DC.CHANNEL_MSK_2),
                               bool(msg.hub_stat & DC.CHANNEL_MSK_3)]
                    set_lst.insert(DC.DC_CH, True)  # channel to chain next hub should always set on
                    set_hub(set_lst)
                    self.send_upstream(DC.make_data(DC.SET_HUB_RTN, hub_chain_id, DC.ACK))
            else:
                if _debug: print(f"DaisyChain: SET_HUB: {msg} not in scope of current chain, relaying cmd to next hub")
                self.send_downstream(msg.raw)
        elif msg.cmd in [DC.GET_HUB_RTN, DC.SET_HUB_RTN] and hub_chain_id > 0:
            if _debug: print(f"DaisyChain: GET/SET_HUB_RTN: {msg}")
            self.send_upstream(msg.raw)
        else:  # all the rest dump into msg queue, mainly for controlling hub to read
            self.q_msg.append(msg)

    def rx_thread(self):
        while self.rx_flag:
            if self.uart_us.any() > 0:  # if there's any data in rx buffer
                self.q_lock.acquire()
                self.q_us.append(self.uart_us.read(HW.DATA_SIZE))
                self.q_lock.release()
            if self.uart_ds.any() > 0:
                self.q_lock.acquire()
                self.q_ds.append(self.uart_ds.read(HW.DATA_SIZE))
                self.q_lock.release()
            if len(self.q_us) > 0:  # processing message from upstream
                self.q_lock.acquire()
                data_raw = self.q_us.popleft()
                self.q_lock.release()
                self.msg_switch(data_raw)
            if len(self.q_ds) > 0:  # processing message from downstream
                self.q_lock.acquire()
                data_raw = self.q_ds.popleft()
                self.q_lock.release()
                self.msg_switch(data_raw)


def version() -> str:
    return f'usb-xwitch ver:{__version__}'


__doc__ = f'''Functions:
         {set_hub.__name__}(list): set hub 4 channels on/off. format: [bool, bool, bool, bool]
         {get_hub.__name__}(): get current hub 4 channels in tuple
         {set_switch.__name__}(int): set switch to channel 1 / 2. starting from 0
         {get_switch.__name__}(): get current switch channel
         {get_adc.__name__}(int): get current switch bus 1 / 2 volrage reading
         {flip_indicator_led.__name__}(): flip indicator led to opposite state
         {ind_led.__name__}(bool): bool. set indicator led status
         '''


_led_ind = Pin(HW.IND_LED, Pin.OUT)
_adc_a1 = ADC(HW.ADC_1_1)
_adc_a2 = ADC(HW.ADC_1_2)
# switch ICs pin power up pre-condition
_sw2_pd = Pin(HW.PD_U2, Pin.OUT)
_sw2_pd.value(HW.LOW)
_sw2_sel = Pin(HW.SEL_U2, Pin.OUT)
_sw3_pd = Pin(HW.PD_U3, Pin.OUT)
_sw3_pd.value(HW.HIGH)  # TODO: debug USB3 comms
_sw3_sel = Pin(HW.SEL_U3, Pin.OUT)
_sw_rel = Pin(HW.SW_REL, Pin.OUT)
# switch manual button control pre-condition
_sw_man = Pin(HW.SW_MAN, Pin.IN, Pin.PULL_UP)
_sw_man.irq(trigger=Pin.IRQ_FALLING, handler=_intr_change_switch)
# HUB IC pin pre-condition
_hub_rst = Pin(HW.HUB_RST, Pin.OUT)
_hub_rst.value(HW.LOW)
# Daisy chain UART set up
_uart = UARTController(HW.UART_U_TX, HW.UART_U_RX, HW.UART_D_TX, HW.UART_D_RX)
_hub = HUBI2C()

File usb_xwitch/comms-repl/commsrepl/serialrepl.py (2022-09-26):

import serial
from threading import Thread, Event
from queue import deque
import time

RX_Q_LINES_TIMEOUT = 3  # Max expected return lines timeout from REPL
EOL = bytes('\r\n'.encode())
END = '>>> '
CR = bytes('\r'.encode())
NL = bytes('\n'.encode())
INPUT_SIGN = bytes('>>> '.encode())


class SerialREPL(object):
    def __init__(self, port_name: str, baud=115200):
        self.serial = serial.Serial(port_name, baudrate=baud, timeout=0)
        if not self.serial.isOpen():
            self.serial.open()
        self.rx_queue = deque(maxlen=10)
        self.rx_th = Thread(target=self.__rx_thread, args=())
        self.rx_th.start()

    def __is_cr_nl_consecutive(self, income_byte: bytes) -> bool:
        """
        check if \r\n received in sequence. i.e. end of a return text line
        :param income_byte:
        """
        self._eol_bytes += income_byte
        if len(self._eol_bytes) < 2:
            return False
        elif len(self._eol_bytes) == 2:
            if self._eol_bytes == EOL:
                self._eol_bytes = bytes()
                return True
            else:
                self._eol_bytes = bytes()
                return False
        else:
            self._eol_bytes = bytes()
            return False

    def __is_input_sign(self, income_byte: bytes) -> bool:
        """
        check if a python input sign received. i.e. >>> sign received. normally indicates that REPL finished text return
        :param income_byte:
        """
        self._input_sign_bytes += income_byte
        if self._input_sign_bytes == INPUT_SIGN:
            self._input_sign_bytes = bytes()
            return True
        elif len(self._input_sign_bytes) > len(INPUT_SIGN):
            self._input_sign_bytes = bytes()
            return False
        return False

    def __rx_thread(self):
        """
        Serial communication receive handling thread
        """
        while self.serial.isOpen():
            if self.serial.inWaiting() > 0:
                ts = time.time()
                line_byte = bytes()
                self._eol_bytes = bytes()
                self._input_sign_bytes = bytes()
                while time.time() - ts < RX_Q_LINES_TIMEOUT and self.serial.inWaiting() > 0:
                    byte_read = self.serial.read()
                    line_byte += byte_read
                    if byte_read in [CR, NL] and self.__is_cr_nl_consecutive(byte_read):
                        self.rx_queue.append(line_byte)
                        break
                    if byte_read in INPUT_SIGN and self.__is_input_sign(byte_read):
                        self.rx_queue.append(line_byte)
                        break

    def close(self) -> None:
        self.serial.close()

    def send(self, cmd: str):
        return self.serial.write(f'{cmd}\r\n'.encode())

    def __del__(self):
        self.close()

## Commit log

2022-06-12 update schematics
    [usb_xwitch.kicad_pcb, usb_xwitch.kicad_sch]
2022-06-18 updated schematics
    [usb_xwitch.kicad_sch]
2022-06-19 add tp; ERC check
    [usb_xwitch.kicad_sch]
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2022-06-20 updated lib using those in this repo
    [usb_xwitch.kicad_sch]
2022-06-20 updated sch with correct lib
    [usb_xwitch.kicad_sch]
2022-06-21 updated led resistor value
    [usb_xwitch.kicad_sch]
2022-06-22 updated pcb and sch
    [usb_xwitch.kicad_pcb, usb_xwitch.kicad_sch]
2022-06-23 changing schematics with one less mux and one more power cycle channel
    [usb_xwitch.kicad_pcb, usb_xwitch.kicad_sch]
2022-06-25 updated rpi connector, pico footprint and board dimension
    [usb_xwitch.kicad_pcb, usb_xwitch.kicad_sch]
2022-06-26 updated 3d model and pcb, sch finalize
    [usb_xwitch.kicad_pcb, usb_xwitch.kicad_sch]
2022-06-27 updated pcb
    [usb_xwitch.kicad_pcb, usb_xwitch.kicad_sch]
2022-06-28 pcb update
    [usb_xwitch.kicad_pcb]
2022-06-30 added Panasonic relay lib for replacement
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2022-07-01 updated pcb to 2 sides
    [usb_xwitch.kicad_pcb, usb_xwitch.kicad_sch]
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2022-07-02 all components within rpi hat dimension
    [usb_xwitch.kicad_pcb, usb_xwitch.kicad_sch]
2022-07-02 fixed q2 not placed properly
    [usb_xwitch.kicad_pcb]
2022-07-02 pcb updated
    [usb_xwitch.kicad_pcb]
2022-07-03 usb gnd changed; wired mux1 all parts
    [usb_xwitch.kicad_pcb, usb_xwitch.kicad_sch]
2022-07-03 pcb in progress
    [usb_xwitch.kicad_pcb]
2022-07-03 pcb routed exc gnd
    [usb_xwitch.kicad_pcb]
2022-07-03 pcb copper poured
    [usb_xwitch.kicad_pcb]
2022-07-07 updated release and manufacture
    [usb_xwitch.kicad_pcb, usb_xwitch_BOM.csv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]
2022-07-08 added manufacture bom with replacement parts
    [manufacture_bom.csv]
2022-07-09 led, res, sw, j footprint changed for manufacture
    [usb_xwitch.kicad_sch]
2022-07-10 update on new packaging
    [usb_xwitch.kicad_pcb, usb_xwitch.kicad_sch]
2022-07-10 udpate pcb
    [usb_xwitch.kicad_pcb]
2022-07-10 updated gerber, bom and pos files
    [usb_xwitch-B_Cu.gbl, usb_xwitch-B_Mask.gbs, usb_xwitch-B_Paste.gbp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]
2022-07-11 manufacture data update
    [manufacture_bom.csv, usb_xwitch_BOM.csv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]
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2022-07-31 added rp2040 lib symbols; updated to 2 sch pages
    [usb_xwitch.kicad_sch]
2022-08-08 added pico sheet 2
    [usb_xwitch.kicad_sch, xwitch_controller.kicad_sch]
2022-08-11 added dc dc step down for rpi2040
    [usb_xwitch.kicad_sch, xwitch_controller.kicad_sch]
2022-08-14 update pico schematics
    [usb_xwitch.kicad_sch, xwitch_controller.kicad_sch]
2022-08-15 update according to pico minimal design
    [usb_xwitch.kicad_sch, xwitch_controller.kicad_sch]
2022-08-16 update crystal symbol/foorprint
    [usb_xwitch.kicad_sch, xwitch_controller.kicad_sch]
2022-08-20 changed rp2040 to official kicad symbol and footprint
    [usb_xwitch.kicad_sch, xwitch_controller.kicad_sch]
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2022-08-27 added usb2 usb3 mux in sch
    [usb_xwitch.kicad_sch]
2022-08-28 updated usb mux wiring
    [usb_xwitch.kicad_sch]
2022-08-28 added shouhan typec in lib
    [usb_xwitch.kicad_sch]
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2022-08-29 more usb-c channels update
    [usb_xwitch.kicad_sch, xwitch_controller.kicad_sch]
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2022-08-31 replaced old pico board connection to embedded rp2040
    [usb_xwitch.kicad_sch, xwitch_controller.kicad_sch]
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2022-09-03 start adding hub ic components and wiring
    [usb_xwitch.kicad_sch]
2022-09-05 added mic2026 power ic
    [usb_xwitch.kicad_sch]
2022-09-08 usb2515b ic power and comms circuit
    [usb_xwitch.kicad_sch, xwitch_controller.kicad_sch]
2022-09-08 updated usb2514 output bus wire
    [usb_xwitch.kicad_sch]
2022-09-10 complete hub and split up sheets
    [power_io.kicad_sch, usb2_hub.kicad_sch, usb3_switch.kicad_sch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]
2022-09-11 added MP1584 symbol and footprint
    [usb_xwitch.kicad_sch]
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2022-09-12 drc checks and renaming
    [power_io.kicad_sch, usb3_switch.kicad_sch, usb_xwitch.kicad_sch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]
2022-09-12 updated power on leds, hub 4 LEDs and misc
    [power_io.kicad_sch, usb2_hub.kicad_sch, usb3_switch.kicad_sch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]
2022-09-14 updated 3d models, broken footprints, pcb re-import
    [power_io.kicad_sch, usb2_hub.kicad_sch, usb3_switch.kicad_sch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]
2022-09-15 fix sch unexpect to gnd; usb to right angle; pcb boarder increased to pi size
    [power_io.kicad_sch, usb2_hub.kicad_sch, usb_xwitch.kicad_pcb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]
2022-09-16 updated sch RESET pin ctrl
    [usb2_hub.kicad_sch, usb_xwitch.kicad_sch]
2022-09-17 correct usb footprints
    [power_io.kicad_sch, usb2_hub.kicad_sch, usb_xwitch.kicad_pcb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]
2022-09-17 pcb layout update and some res package changed
    [power_io.kicad_sch, usb_xwitch.kicad_pcb, usb_xwitch.kicad_sch]
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2022-09-20 rearrange layout to fit
    [usb_xwitch.kicad_pcb]
2022-09-21 component layout all in board
    [usb_xwitch.kicad_pcb, usb_xwitch.kicad_sch, xwitch_controller.kicad_sch]
2022-09-21 update label for easy routing differential pair
    [usb2_hub.kicad_sch, usb3_switch.kicad_sch, usb_xwitch.kicad_pcb]
2022-09-23 wrong wiring fixed on usb switch; update layout
    [power_io.kicad_sch, usb3_switch.kicad_sch, usb_xwitch.kicad_pcb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]
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2022-09-24 switch downstream differential pairs
    [usb_xwitch.kicad_pcb]
2022-09-25 new differential layout meth
    [usb_xwitch.kicad_pcb]
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2022-09-30 more polygon area fill
    [usb_xwitch.kicad_pcb]
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2022-10-02 more IC layout updates
    [usb_xwitch.kicad_pcb, usb_xwitch.kicad_sch]
2022-10-03 gnd layer and pwr layer added
    [usb_xwitch.kicad_pcb]
2022-10-04 updated drc annular clearance
    [usb_xwitch.kicad_pcb]
2022-10-05 plenty pf DRC fixing
    [usb_xwitch.kicad_pcb]
2022-10-06 clear drc and warnings
    [usb_xwitch.kicad_pcb]
2022-10-06 v02 gerber and manufacturing
    [manufacture_bom.csv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]
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2022-10-10 added more DNF components for easy debugging
    [power_io.kicad_sch, usb2_hub.kicad_sch, usb3_switch.kicad_sch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]
2022-10-12 more further away vias; new release BoM, Gerber, CPL
    [usb_xwitch-B_Cu.gbl, usb_xwitch-B_Mask.gbs, usb_xwitch-B_Paste.gbp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]
2022-10-16 updated cpl.csv for quote
    [usb_xwitch-all-pos.csv]
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2022-11-06 correct switch set check
    [main.py]
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
